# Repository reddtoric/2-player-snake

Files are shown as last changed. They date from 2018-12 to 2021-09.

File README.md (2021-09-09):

# 2-player-snake

2 player snake game in C++ using Arduino Mega, 32x32 LED matrix, custom shield, and two custom 4-button controllers for Adv. Additive Manufacturing (UIC ENGR 294) with updated case.

</br>
<p float="left">
GIF of 2p snake part1
GIF of 2p snake part2
</p>

[Original GIF #1](https://media.giphy.com/media/iEMkRfB8JyjEhcMhLR/giphy.gif) | 
[Original GIF #2](https://media.giphy.com/media/J6tbl7obMBHApaVlm7/giphy.gif)

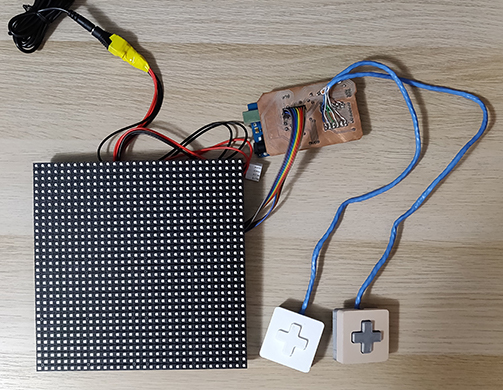
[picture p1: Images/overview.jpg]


</br></br>

<!-- TOC -->

## Table of Contents

- [2-player-snake](#2-player-snake)
  - [D-pad Controller PCB](#d-pad-controller-pcb)
  - [LED Shield for Arduino Mega](#led-shield-for-arduino-mega)
  - [Case](#case)
  - [Updated Case](#updated-case)

<!-- /TOC -->

(Few more pictures included in _Images/_)

## D-pad Controller PCB

Manually figuring out the routes for all 4 buttons.

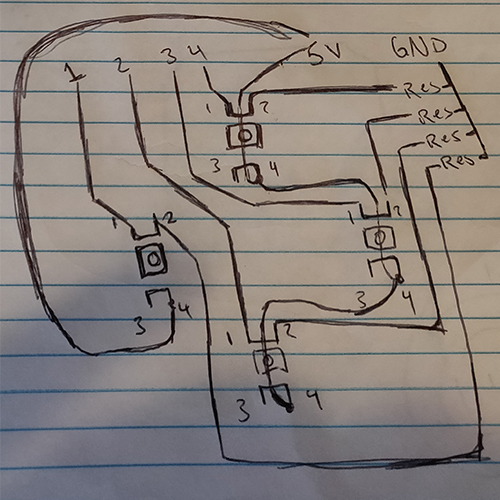
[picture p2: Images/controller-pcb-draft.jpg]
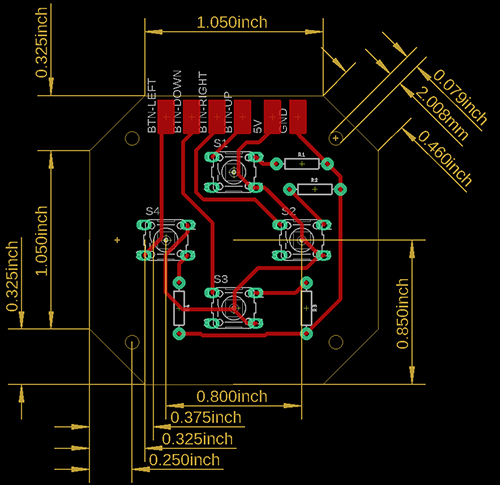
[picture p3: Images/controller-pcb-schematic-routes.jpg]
 
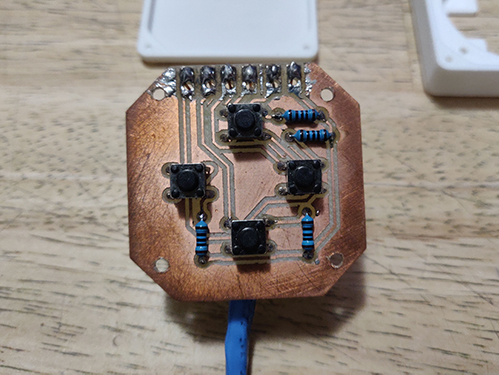
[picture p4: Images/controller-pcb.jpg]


Yes, I know the soldering is ugly.

## LED Shield for Arduino Mega

Also manually routed the shield. Here is the mapping of the 16 pin connector socket for LED matrix and the routes to the Arduino Mega pinouts. The correct mapping might be the horizontal mirrored version; I didn't have a connector cable.

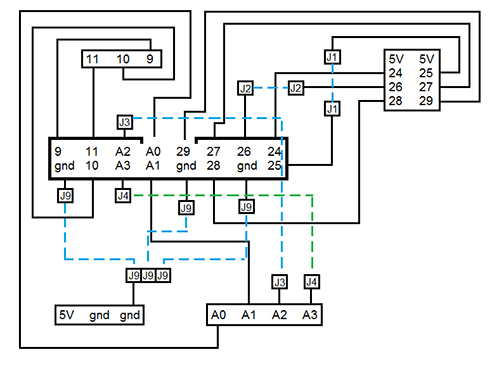
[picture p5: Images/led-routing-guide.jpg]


I only had access to single sided PCB so red PCB routes are on the top/main side and blue routes are on the back that had to be manually connected with wires.

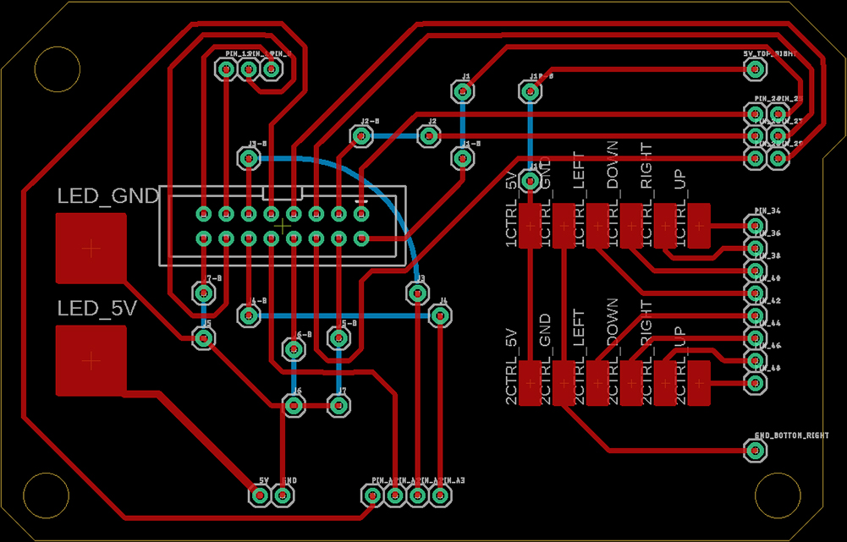
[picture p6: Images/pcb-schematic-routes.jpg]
 </br>
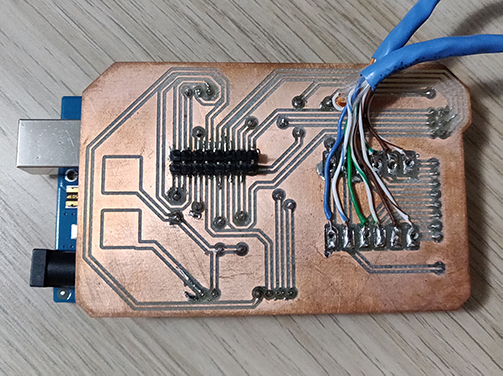
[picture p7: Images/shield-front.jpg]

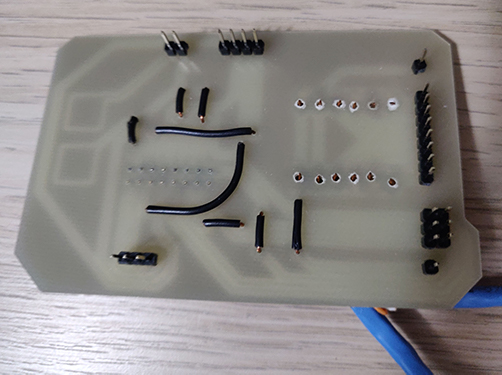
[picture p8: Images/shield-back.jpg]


## Case

Planning and designing the controller cases.

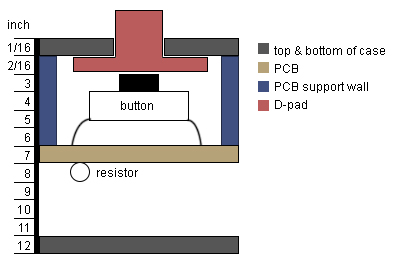
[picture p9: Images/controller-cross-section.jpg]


(Partially) Initial design. I forgot the divot where the soldering on the PCB takes up space. In the original case, you'll see I melted it. Screw holes and cable hole are not in the CAD because I didn't have enough time to make sure they're were they should be and decided to just drill them.

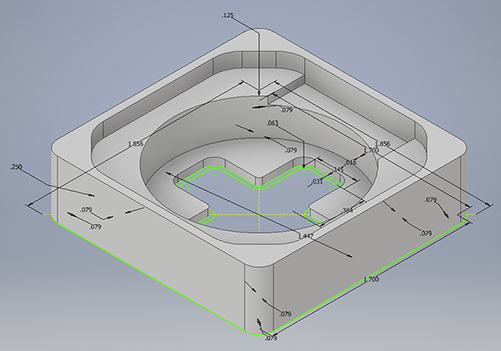
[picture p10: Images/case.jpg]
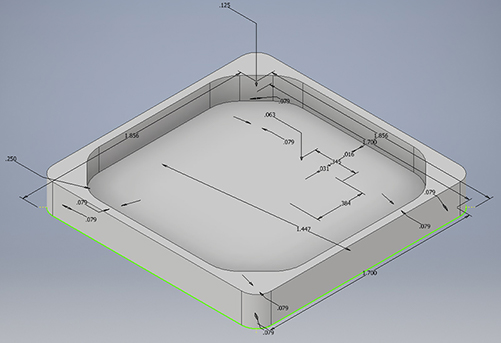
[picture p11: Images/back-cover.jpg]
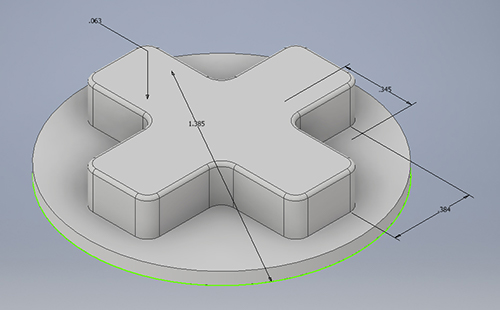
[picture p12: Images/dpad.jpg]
  

Putting it all together.

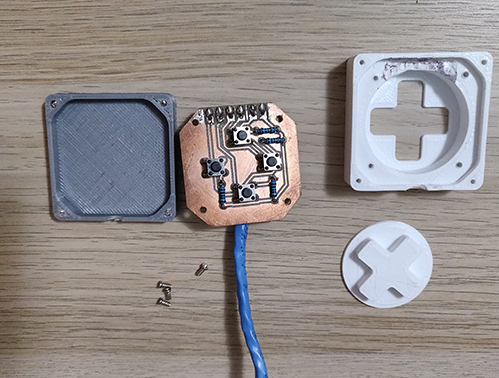
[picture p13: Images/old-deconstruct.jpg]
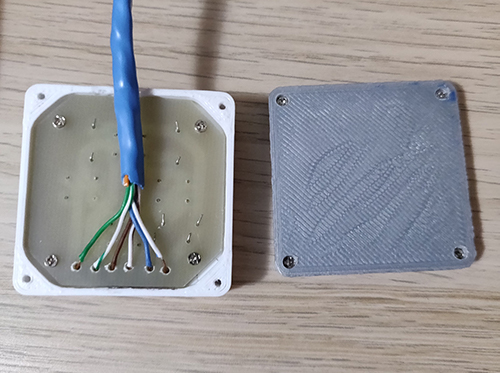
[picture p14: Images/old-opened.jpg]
 

## Updated Case

Added minor changes to the case design. Filet edges, screw holes, tighter tolerances, hole for ethernet cable, and printed with higher quality settings.

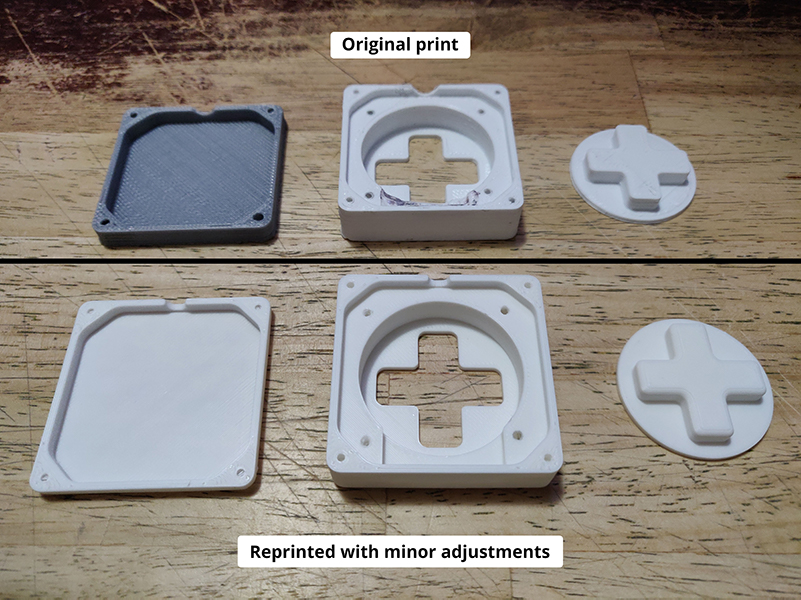
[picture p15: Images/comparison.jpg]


Old:

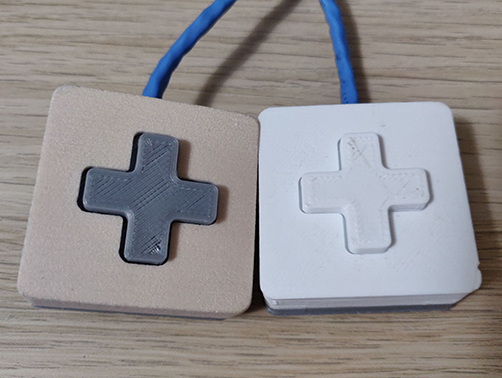
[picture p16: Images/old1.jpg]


New:

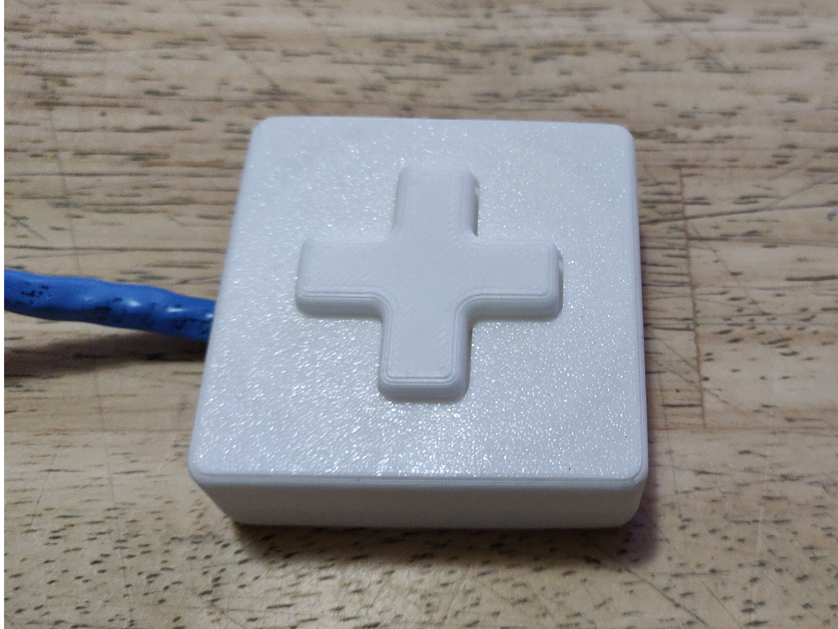
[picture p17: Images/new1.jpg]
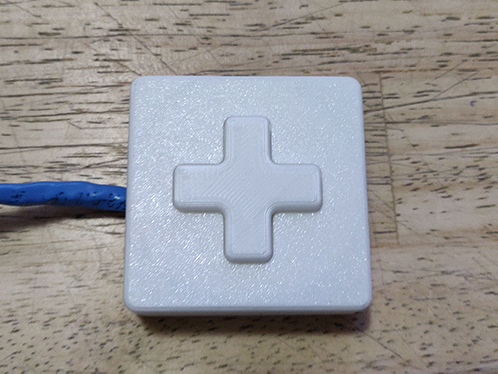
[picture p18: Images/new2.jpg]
 </br>
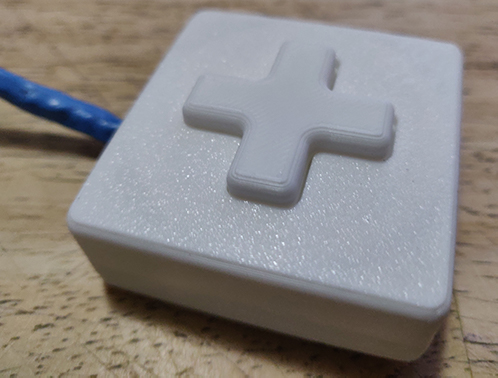
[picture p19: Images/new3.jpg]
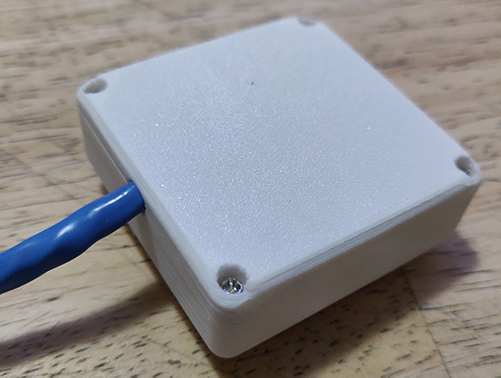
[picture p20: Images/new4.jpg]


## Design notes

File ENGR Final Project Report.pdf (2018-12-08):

University of Illinois at Chicago

# Two-player Snake

ENGR 294 Final Project

Edward Hughes

ENGR 294 Adv. Additive Manufacturing

Dylan Lynch

Fall 2018

ENGR 294 Final Proj. – 2 Player Snake

## Contents

Introduction | 1
Design Details | 1
Overview | 1
Shield | 1
Controller | 4
Controller Case | 6
Arduino Mega Case | 7
Results | 8
Future Ideas | 8

## Figures

Figure 1: Overview | 1
Figure 2: LED Routing Guide | 2
Figure 3: Shield Board | 2
Figure 4A: Shield Schematic | 3
Figure 5: Controller Board | 4
Figure 6: Controller Schematic | 4
Figure 7: First draft of the design for the controller board | 5
Figure 8: Controller Cross Section | 6
Figure 9: Case | 6
Figure 10: Back Cover | 7
Figure 11: D-pad | 7
Figure 12: Arduino Mega Case Design Sketch | 8

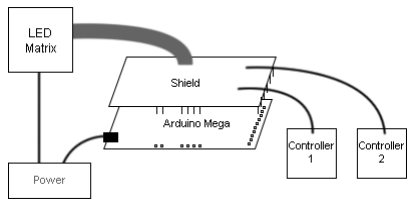
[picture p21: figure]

Edward Hughes | 1

## Introduction

This final project is a two-player snake game using the Arduino Mega and a 32x32 RGB LED matrix.

The classic Snake game on the iconic Nokia is the inspiration for this project. There are plenty of implementations and multiplayer implementations of Snake. The muliplayer ones I have seen have cartoon-like graphics and/or have 360 directional controls which I did not like. Since these implementations didn’t give me the same feeling as the first Snake game I’ve played, I’ve always wanted to make one that was similar to the Snake game I played. I decided to make it two-player because single-player games becomes boring for me.

## Design Details

### Overview

The project consists of a 32x32 RGB LED matrix and 2 PCB boards with 4 buttons each connected to a shield and Arduino Mega.

Figure 1: Overview

### Shield

The shield is the circuit board to connect the LED matrix and the 2 controllers with the Arduino Mega. It’s a single-sided PCB with 8 wires soldered on the back.

I designed the shield in (what I think is) an unconventional. Instead of using the proper parts in the schematic/board or using the appropriate tools to have a route that needed to be routed on the bottom side of the board, I used 2 1-pin-connectors so I can solder a wire to connect them. The bottom (blue) routes shown in Figure 3 show where are the 8 wires should be and they are not actually connected in the schematic/board. These connectors are labeled “J#” and “J#-B” so I know which pair of holes match together.

Figure 2 is a guide I made using Microsoft Paint to help me with how to route each connections for the LED connections. The numbers pairs here are different.

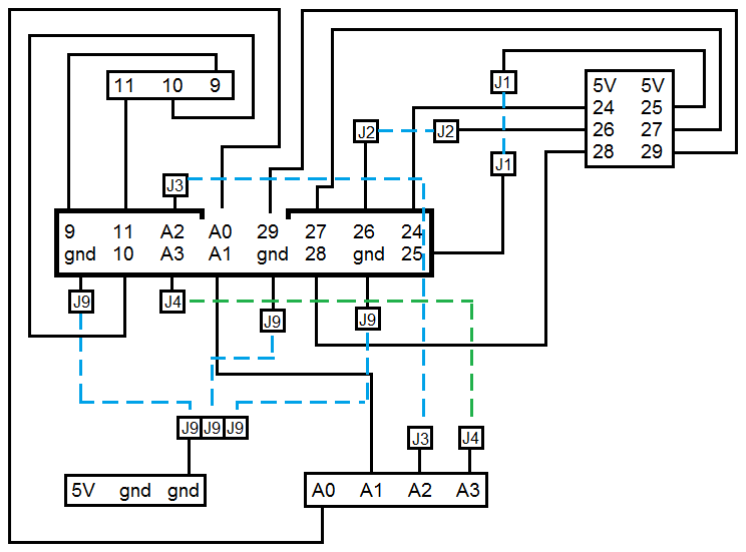
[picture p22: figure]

Figure 2: LED Routing Guide

The shield is a double-sided design because most if not all of the LED connections needed to be connected to certain pins on the Mega. The placement and orientation of the 2x8 headers for the LED matrix is to have each connectors close to the correct pins they are supposed to go and with the least amount of bottom routes needed. The design is not exhaustive so it may be possible to have less than 8 bottom routes. The placement of the 12 pads for the 2 controllers is to be as close to the pins without bottom routes. I learned that I should use connector parts instead of pads when possible because soldering wires on the pads were awfully difficult. I included 2 extra large pads that I created myself on the left in case I were to solder the LED power and ground connectors on the shield.

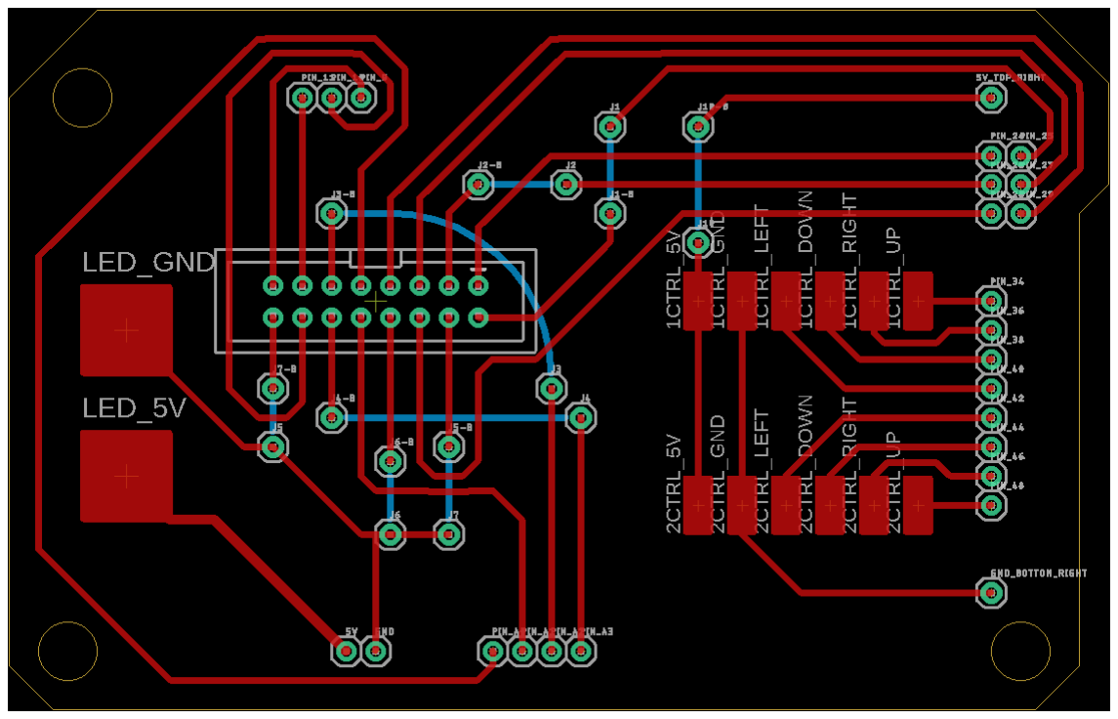
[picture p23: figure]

Figure 3: Shield Board

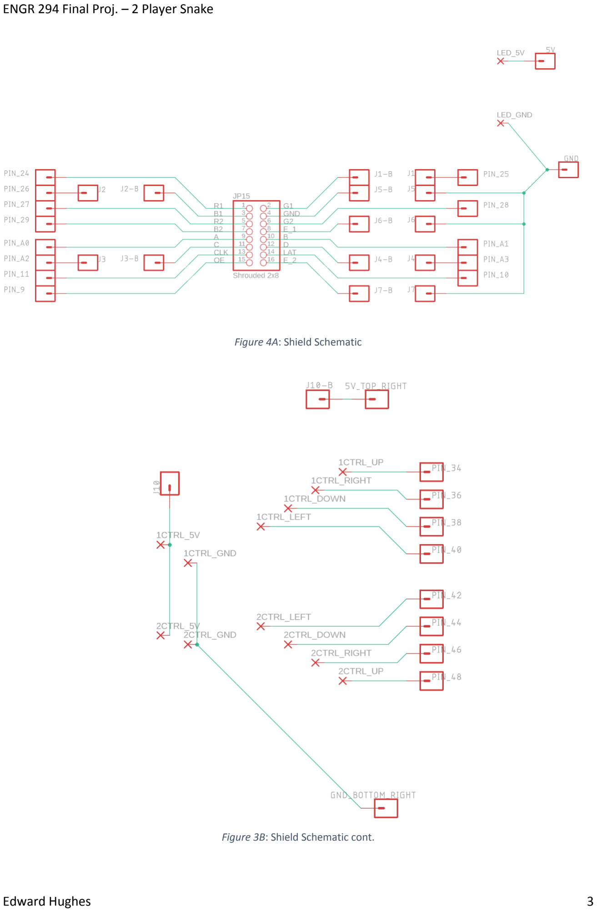
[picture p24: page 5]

Figure 4A: Shield Schematic

Figure 3B: Shield Schematic cont.

### Controller

There are 2 controller PCBs that are exactly the same. They have 4 push buttons each for the 4 possible directions. The buttons are placed so they correspond to the 4 directions and the resistors are placed relatively close to the connected buttons. The pads are placed in that specific “weird” order because it allowed the routes to only be on top side of the PCB. Shown in figure 5, the connections for the left button (S4) are mirror on the horizontal axis compared to the other 3 buttons. This is because initially all the resistors were located on the top right corner which would require either the power and ground connection to be placed on the bottom side of the board. I moved rearranged the resistors from all being in the top right corner to where they are now so the board can be as small as it is now, squared footprint, and with the 4 buttons centered.

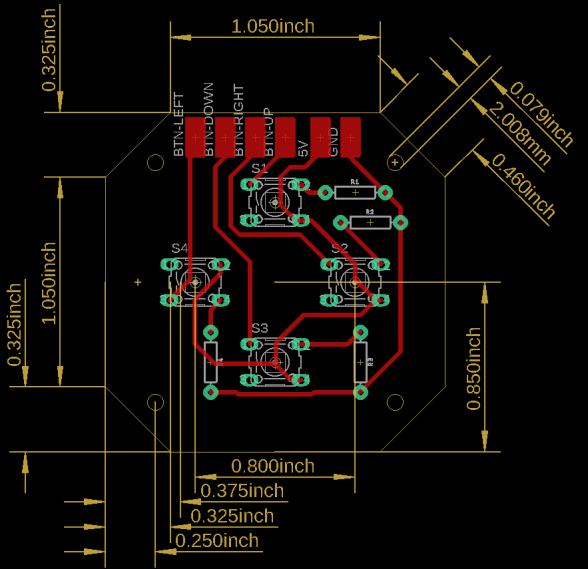
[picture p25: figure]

Figure 5: Controller Board

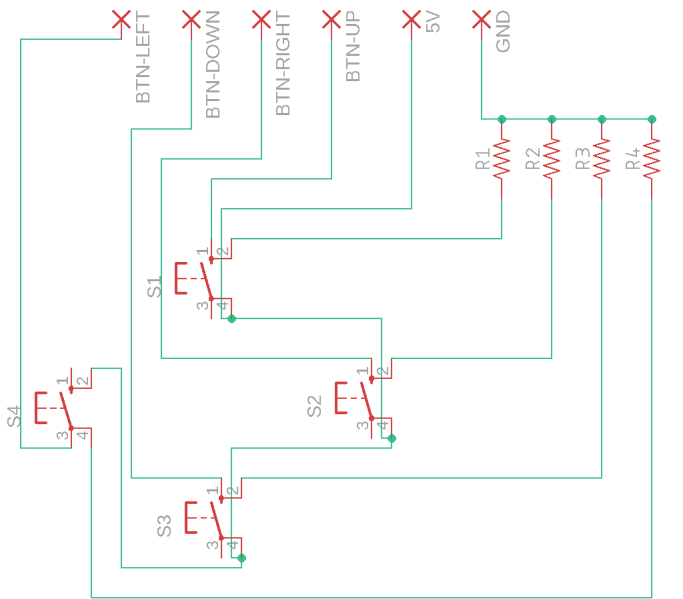
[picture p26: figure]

Figure 6: Controller Schematic

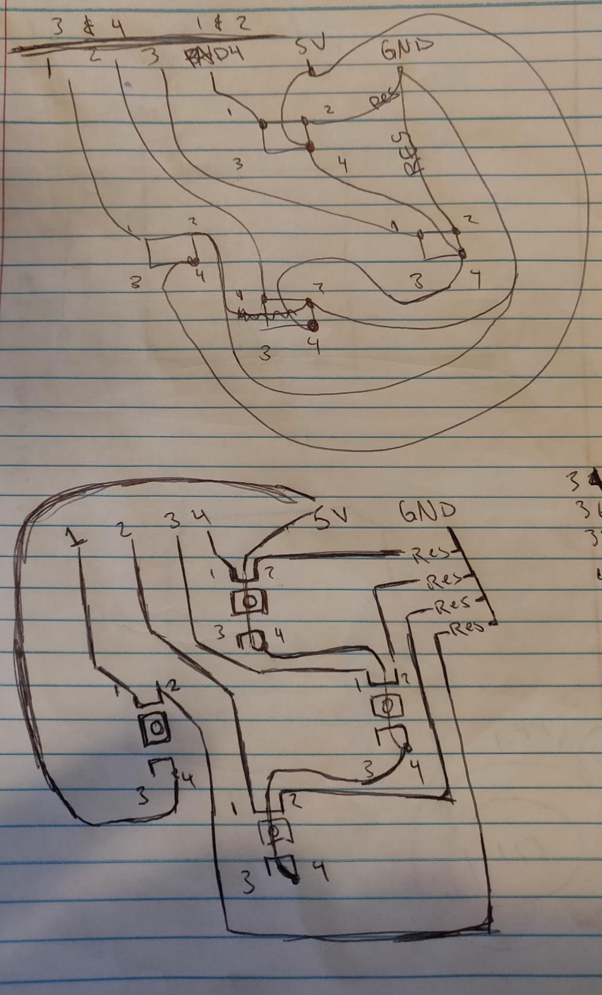
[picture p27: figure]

Figure 7: First draft of the design for the controller board

### Controller Case

There are 3 parts to each case; the main part, the back cover, and the D-pad. The main part is where the controller PCBs would be attached onto. For the most part, it is symetrical on the X and Y axis. The small cutout area on the top right of Figure 9 was added after I realized the 6 pad connections for the controllers were in the way. The design of the case was to be fitted to the controller circuit board and as small as possible. I included about 1/16” or 1/32” of wiggle room for the D-pad and the slot that the circuit board fits in.

Figure 8, is a cleaned up version of a sketch I made to help me figure out what heights I need for the extrusions for the case. In this diagram, the outer side walls are not drawn. The resistor is at the 8/16” mark because that’s where I initially wanted them to be but I end up putting them on the same side as the buttons. With this diagram, the max height of the D-pad would be between 3/16” and 4/16”, I decided to make it 4/16”.

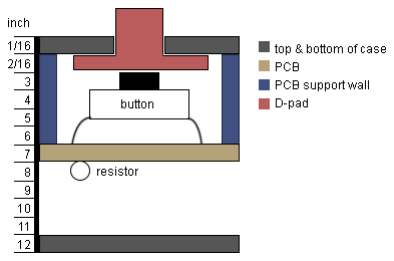
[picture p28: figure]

Figure 8: Controller Cross Section

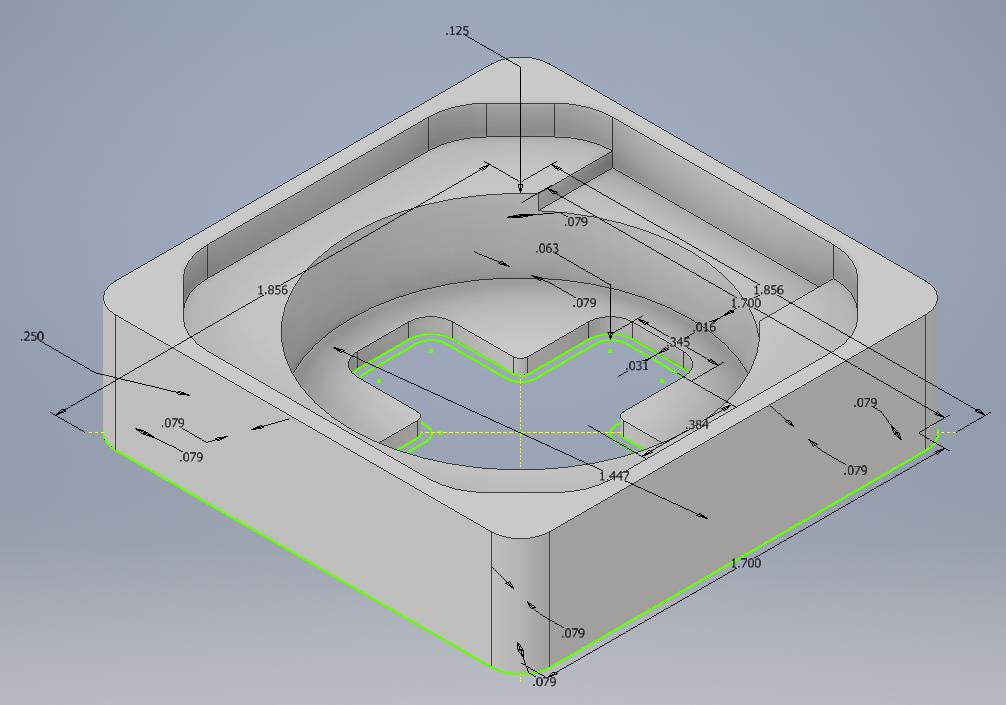
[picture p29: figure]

Figure 9: Case

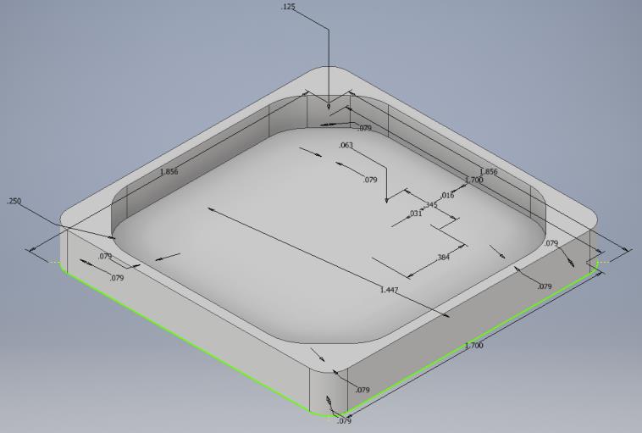
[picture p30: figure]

Figure 10: Back Cover

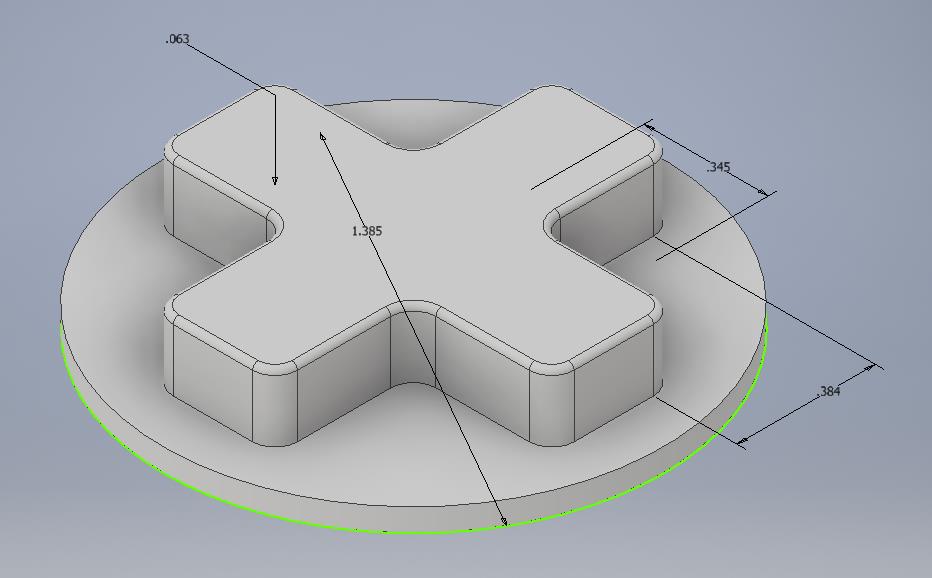
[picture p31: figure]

Figure 11: D-pad

Only 1 of the main part is CNC milled using high density foam. The other is 3D printed along with both back covers and both D-pads.

The Inventor part for the case has toolpath settings for high density foam. The Inventor part for the back cover has toolpath settings for HDPE even though HDPE was not used.

### Arduino Mega Case

Or the lack of a case. I did not create a case for the Arduino Mega, shield, and LED matrix. But if I did, I think it would fit around the Arduino Mega and shield only. The 2 ethernet wires used for connecting the controllers to the case would come out from the top right area of the Mega. And the LED matrix would be attached on the case with 4 arms that would somewhat resemble a speaker.

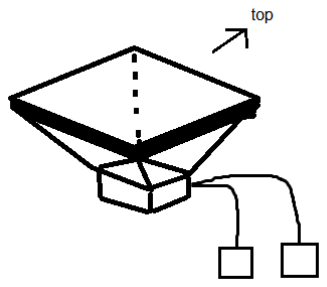
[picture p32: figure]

Figure 12: Arduino Mega Case Design Sketch

## Results

The circuit works and testers enjoyed the game. I enjoyed designing and creating the CAD files, program, and circuitry. Three other people outside of MakerSpace and class tested the game and liked the game and the two-player idea.

## Future Ideas

If I thought about and decided on this idea earlier, I would have been able to get RF modules and the appropriate chips to make the controllers wireless while keeping the designs fairly small. Other alternatives that don’t make sense but still works is to use small bluetooth modules and small microcontrollers to drive the 2 controllers.

I can polish up the coding for this two-player snake and also create a starting menu and a better gameover menu. Selection of colors and speed. Multiple food/apples. More than 2 players. As well as creating other games like Pong, Tetris, Pac-Man, and Tron.

Seeing the amount of positive feedback, I’m inspired and motivated to create a PC/Mac/Linux game based on this using Unity (game engine). The game would most likely have 2D “boards” in a 3D world where you can teleport between the boards. The boards are not all rectangular, they could be different shapes.

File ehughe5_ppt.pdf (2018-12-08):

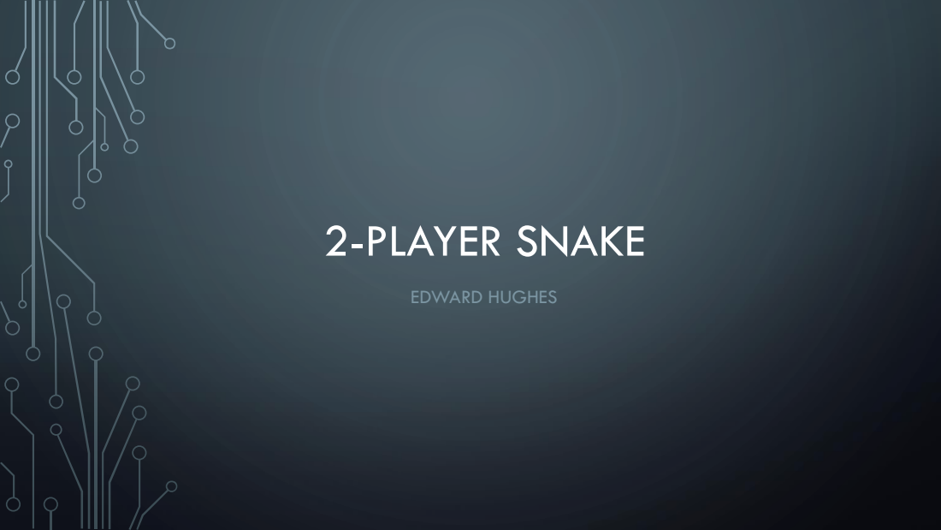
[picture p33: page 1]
2-PLAYER SNAKE; EDWARD HUGHES

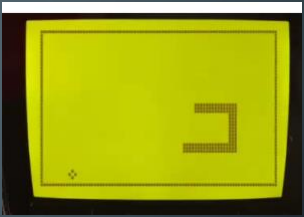
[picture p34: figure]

## INSPIRATION

- Classic Snake game on the iconic

Nokia phone

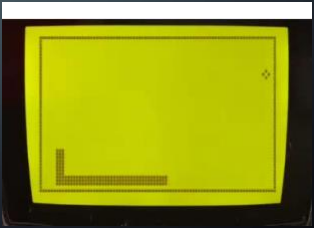
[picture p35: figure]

- Single player is boring so that’s why

this is 2-player

## BIG PICTURE

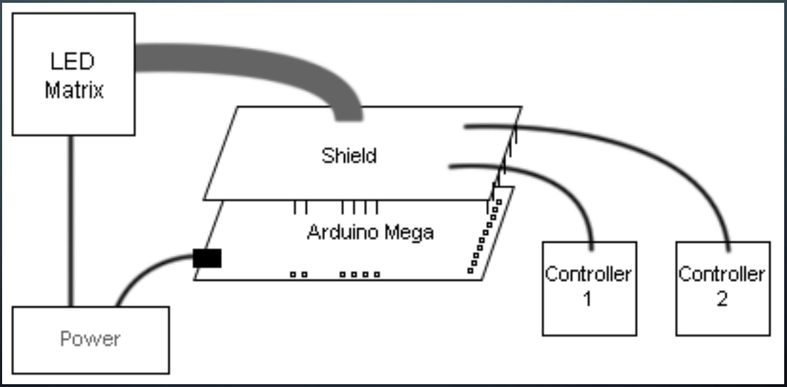
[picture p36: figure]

## SHIELD DESIGN

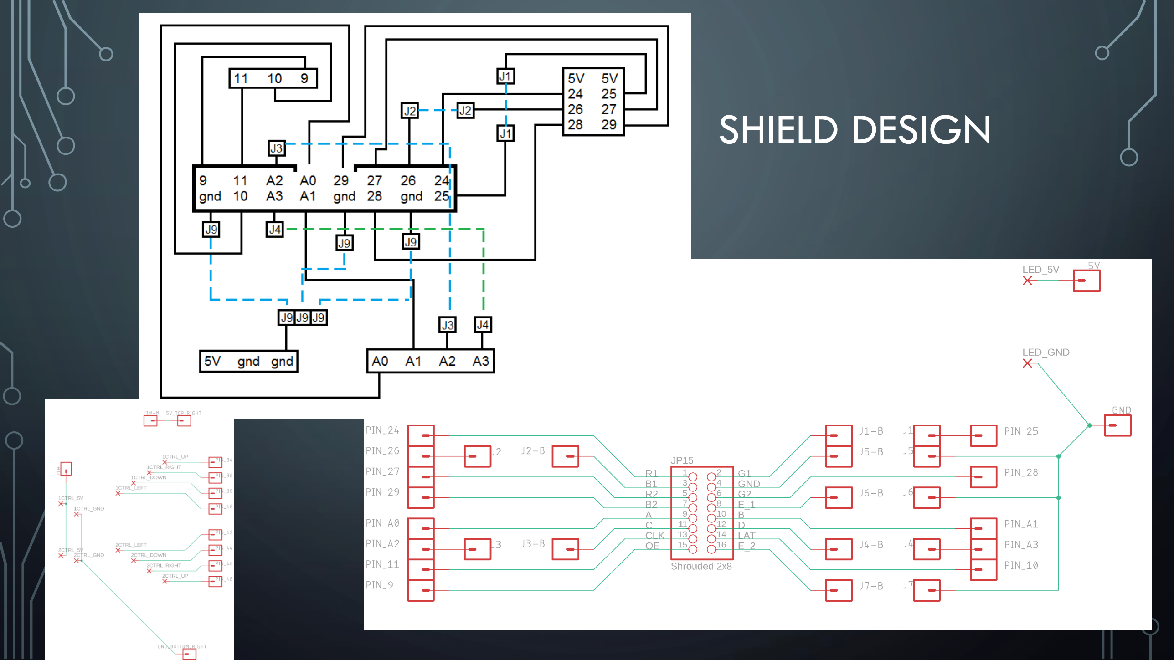
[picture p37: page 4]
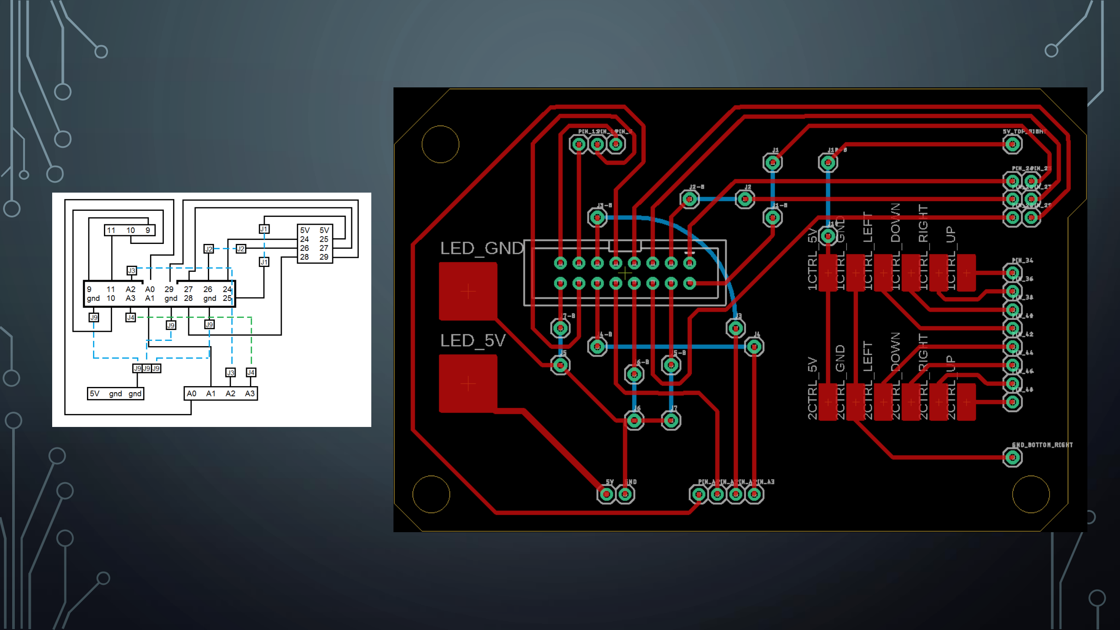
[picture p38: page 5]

## CONTROLLER PCB DESIGN

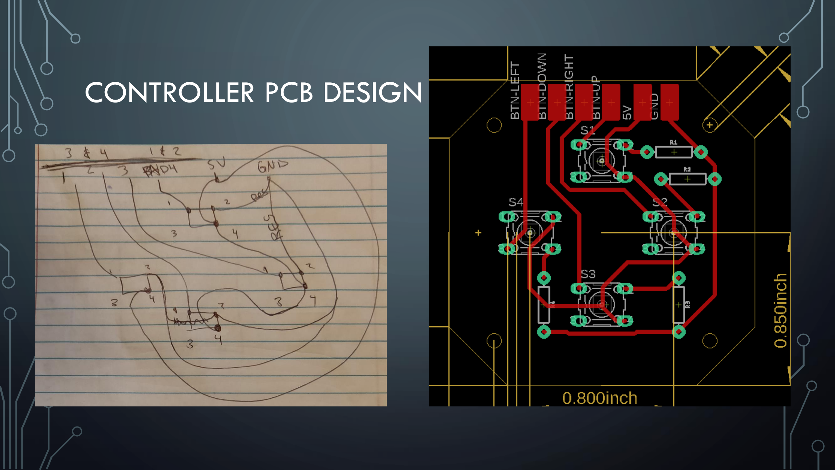
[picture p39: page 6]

## CONTROLLER CASE DESIGN

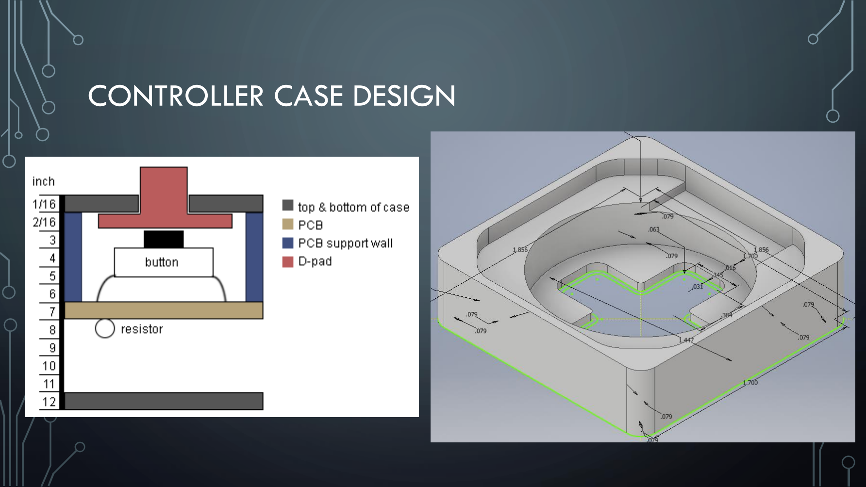
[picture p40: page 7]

## 3 PIECE CASE

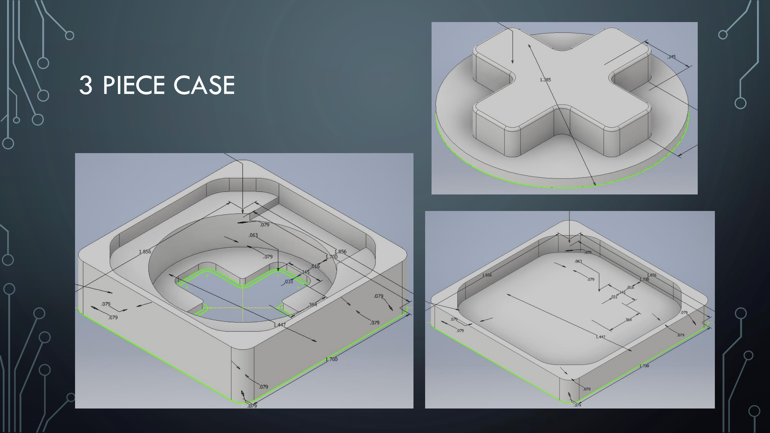
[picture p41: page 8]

## FUTURE IDEAS

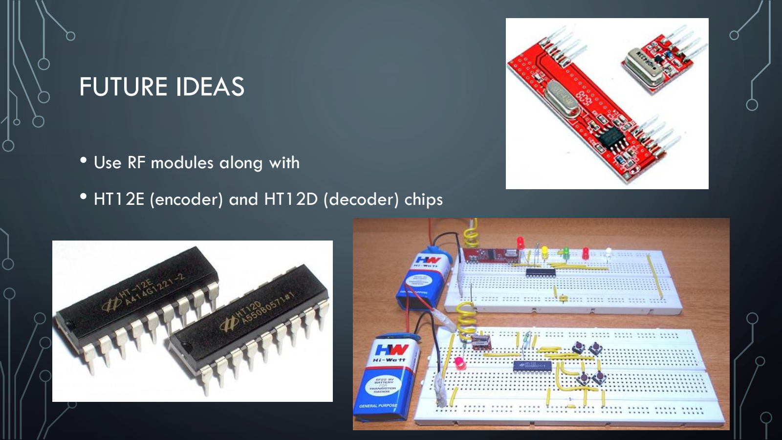
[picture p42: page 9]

- Use RF modules along with
- HT12E (encoder) and HT12D (decoder) chips

## FUTURE IDEAS 2

- Polish the code and add selection of colors, speed, difficulty
- Add multiple food and more than 2 players
- Implement other games like Tron, Pac-Man, Tetris, and Pong

## FUTURE IDEAS 3

- Make PC/Mac/Linux game based on this using Unity (game engine) and

inspired by 4D chess (the “teleporting” part)

- Instead of a plain vanilla 2D board or cartoonlike graphics
- 2D boards placed in a 3D world and to travel between the 2D boards,

players go to a certain spot to teleport to corresponding teleport terminal

- Non rectangular board shapes
- Information about this will be published on EdDevs.com (if I really make it)

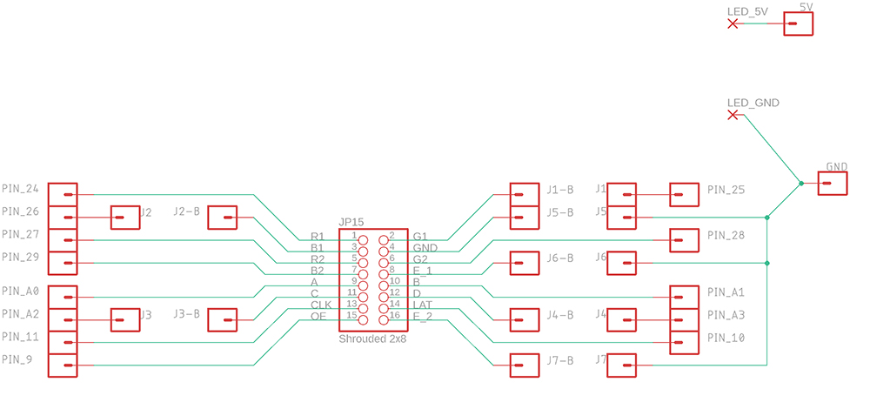
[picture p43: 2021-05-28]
Images/shield-schematic.jpg

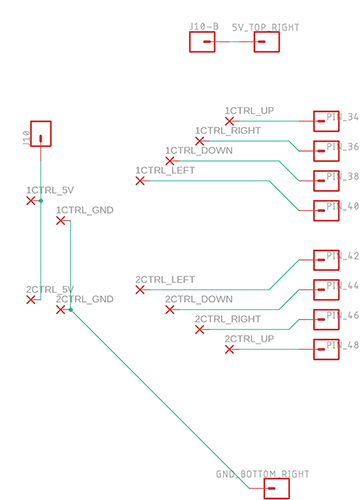
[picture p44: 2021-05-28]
Images/shield-schematic-2.jpg

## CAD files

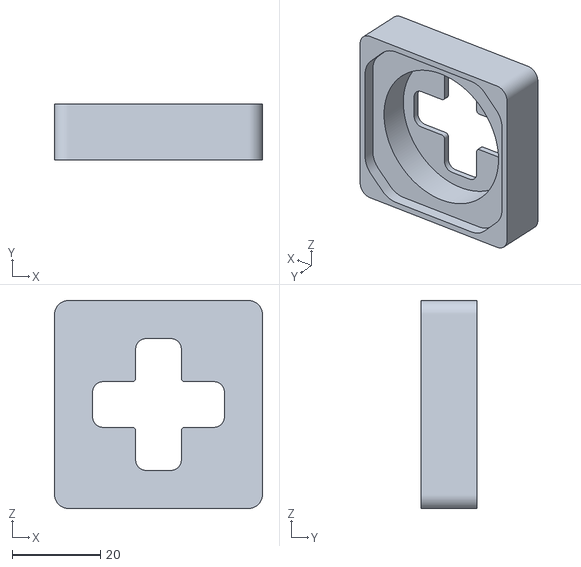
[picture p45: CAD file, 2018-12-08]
CAD Designs/3D Print Files/SnakeControllerCase_v3_withCNCsetup.stl
47.1 x 12.7 x 47.1

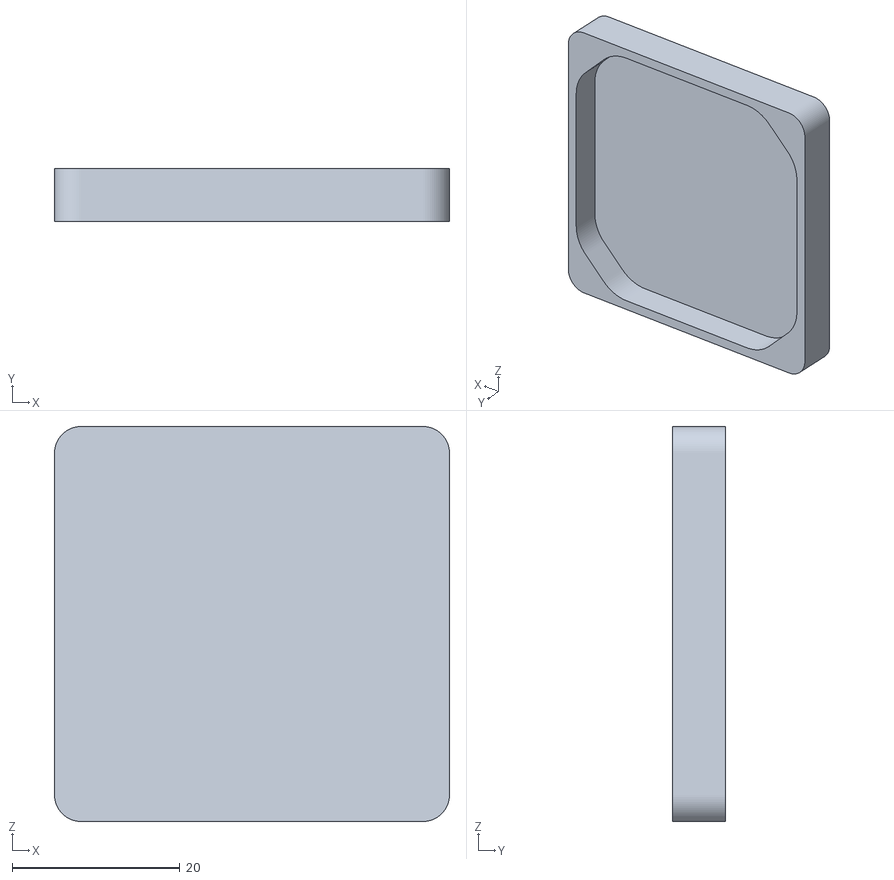
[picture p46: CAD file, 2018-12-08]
CAD Designs/3D Print Files/SnakeControllerCaseBackCover_v4_withCNCsetup.stl
47.1 x 6.35 x 47.1

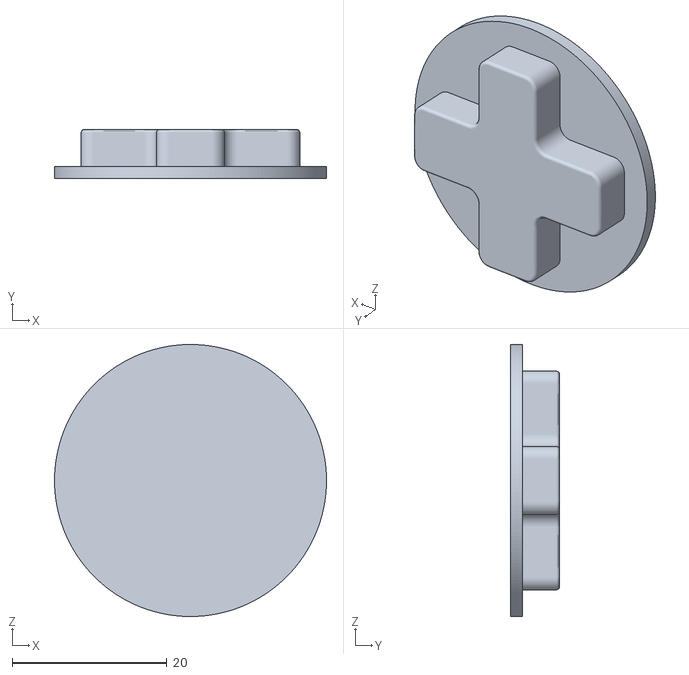
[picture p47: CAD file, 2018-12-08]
CAD Designs/3D Print Files/SnakeControllerDPad_v3.stl
35.2 x 6.35 x 35.2

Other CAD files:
Archive/CAD Designs/SnakeControllerCaseBackCover_v4_withCNCsetup.ipt
Archive/CAD Designs/SnakeControllerCase_v4_withCNCsetup.ipt
Archive/CAD Designs/SnakeControllerDPad_v3.ipt
CAD Designs/SnakeControllerCaseBackCover_v4_withCNCsetup.ipt
CAD Designs/SnakeControllerCase_v4_withCNCsetup.ipt
CAD Designs/SnakeControllerDPad_v3.ipt

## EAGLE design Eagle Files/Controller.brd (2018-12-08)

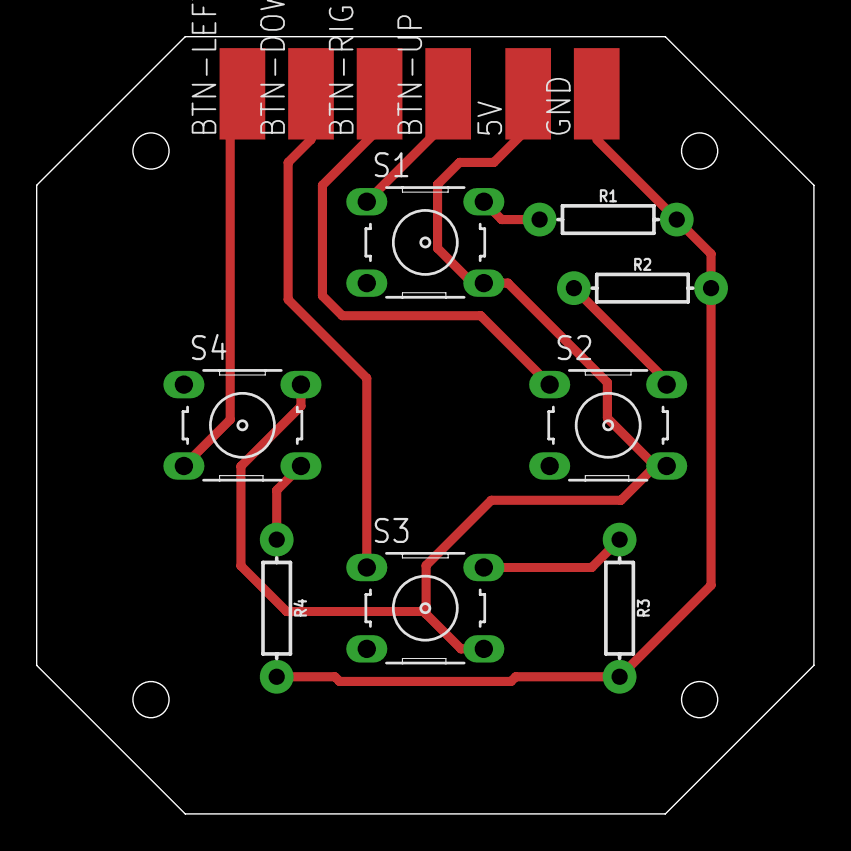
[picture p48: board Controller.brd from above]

Board: 2 copper layers, 43.2 x 43.2 mm, 14 parts (0 on the bottom side), 10 nets.

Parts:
5V: SMD2,54-5,08
BTN-DOWN: SMD2,54-5,08
BTN-LEFT: SMD2,54-5,08
BTN-RIGHT: SMD2,54-5,08
BTN-UP: SMD2,54-5,08
GND: SMD2,54-5,08
R1, R2, R3, R4: AXIAL-0.3
S1, S2, S3, S4: B3F-10XX

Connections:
unnamed: BTN-DOWN.1, S3.1
unnamed: BTN-RIGHT.1, S2.1
unnamed: BTN-UP.1, S1.1
unnamed: BTN-LEFT.1, S4.3
unnamed: GND.1, R1.P$2, R2.P$2, R3.P$2, R4.P$2
unnamed: R1.P$1, S1.2
unnamed: R2.P$1, S2.2
unnamed: R3.P$1, S3.2
unnamed: R4.P$1, S4.4
unnamed: 5V.1, S1.4, S2.4, S3.4, S4.2

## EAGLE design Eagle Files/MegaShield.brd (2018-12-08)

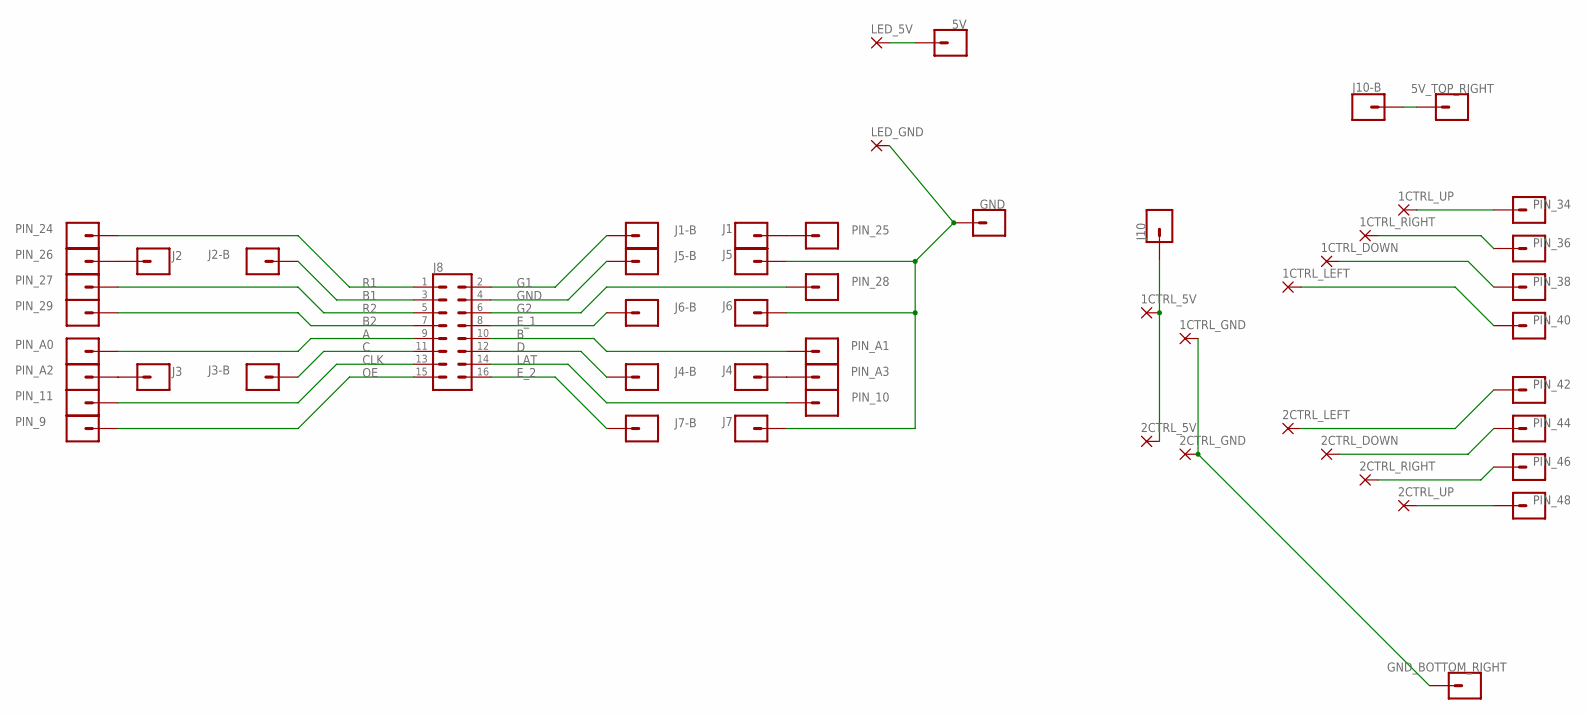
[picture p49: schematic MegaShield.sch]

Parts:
1CTRL_5V, 1CTRL_DOWN, 1CTRL_GND, 1CTRL_LEFT, 1CTRL_RIGHT, 1CTRL_UP, 2CTRL_5V, 2CTRL_DOWN, 2CTRL_GND, 2CTRL_LEFT, 2CTRL_RIGHT, 2CTRL_UP: PADSMALL; SMD2,54-5,08
5V, 5V_TOP_RIGHT: CONN_01; 1X01
GND: CONN_01; 1X01
GND_BOTTOM_RIGHT: CONN_01; 1X01
J1, J1-B, J2, J2-B, J3, J3-B, J4, J4-B, J5, J5-B, J6, J6-B, J7, J7-B, J10, J10-B: CONN_01; 1X01
J8: CONN_08X2_SHROUD; 2X8-SHROUDED_LOCK
LED_5V: PAD_EXLARGE; SMD_EXLARGE
LED_GND: PAD_EXLARGE; SMD_EXLARGE
PIN_9, PIN_10, PIN_11, PIN_24, PIN_25, PIN_26, PIN_27, PIN_28, PIN_29, PIN_34, PIN_36, PIN_38, PIN_40, PIN_42, PIN_44, PIN_46, PIN_48: CONN_01; 1X01
PIN_A0, PIN_A1, PIN_A2, PIN_A3: CONN_01; 1X01

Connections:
A: J8.9, PIN_A0.1
B: J8.10, PIN_A1.1
B1: J2-B.1, J8.3
B2: J8.7, PIN_29.1
C: J3-B.1, J8.11
CLK: J8.13, PIN_11.1
D: J4-B.1, J8.12
E_1: J6-B.1, J8.8
E_2: J7-B.1, J8.16
G1: J1-B.1, J8.2
G2: J8.6, PIN_28.1
GND: J5-B.1, J8.4
LAT: J8.14, PIN_10.1
unnamed: J2.1, PIN_26.1
unnamed: J3.1, PIN_A2.1
unnamed: J1.1, PIN_25.1
unnamed: 5V.1, LED_5V.P$1
unnamed: GND.1, J5.1, J6.1, J7.1, LED_GND.P$1
unnamed: J4.1, PIN_A3.1
unnamed: 1CTRL_UP.1, PIN_34.1
unnamed: 1CTRL_RIGHT.1, PIN_36.1
unnamed: 1CTRL_DOWN.1, PIN_38.1
unnamed: 1CTRL_LEFT.1, PIN_40.1
unnamed: 2CTRL_UP.1, PIN_48.1
unnamed: 2CTRL_RIGHT.1, PIN_46.1
unnamed: 2CTRL_DOWN.1, PIN_44.1
unnamed: 5V_TOP_RIGHT.1, J10-B.1
unnamed: 1CTRL_5V.1, 2CTRL_5V.1, J10.1
unnamed: 1CTRL_GND.1, 2CTRL_GND.1, GND_BOTTOM_RIGHT.1
unnamed: 2CTRL_LEFT.1, PIN_42.1
OE: J8.15, PIN_9.1
R1: J8.1, PIN_24.1
R2: J8.5, PIN_27.1

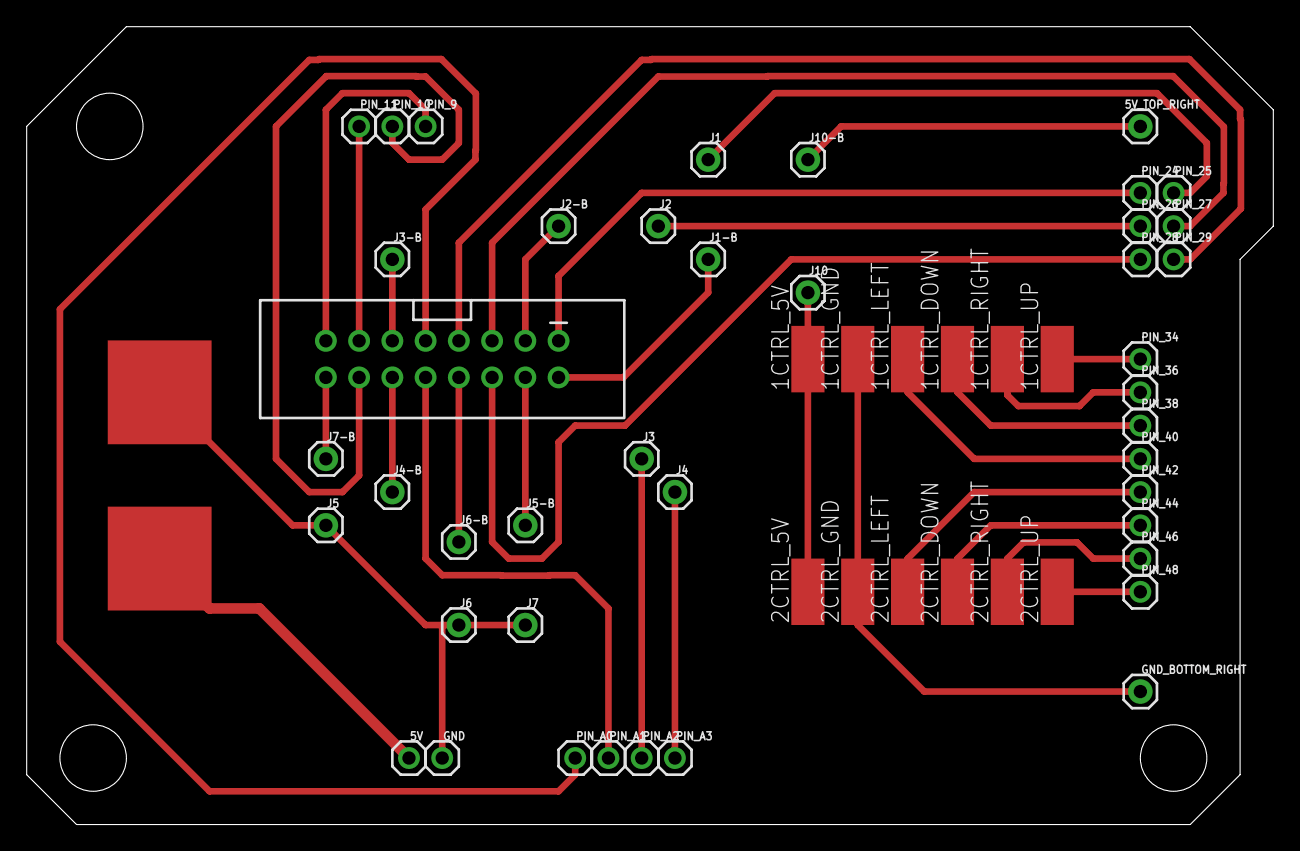
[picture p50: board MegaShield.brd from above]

Board: 2 copper layers, 95.2 x 61.0 mm, 56 parts (0 on the bottom side), 33 nets.

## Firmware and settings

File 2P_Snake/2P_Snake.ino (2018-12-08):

#include <LinkedList.h> //https://github.com/ivanseidel/LinkedList
#include <gamma.h>
#include <RGBmatrixPanel.h>


//speed of game & frame rate
//lower number = faster, higher number = slower
int speed = 150;

//dimension of led matrix
#define MAX_X 32
#define MAX_Y 32



//player 1 d-pad
#define P1_LEFT 36
#define P1_DOWN 34
#define P1_RIGHT 40
#define P1_UP 38

//player 2 d-pad
#define P2_LEFT 46
#define P2_DOWN 48
#define P2_RIGHT 42
#define P2_UP 44

enum Direction {
  up,
  down,
  left, 
  right
};

typedef struct Position {
  int x;
  int y;
};

typedef struct Player{
  LinkedList <Position> snake;
  int length;
  Direction direction;
};

//Arduino Mega pins
RGBmatrixPanel matrix(A0, A1, A2, A3, 11, 10, 9, false);

bool gameover = false;

Player p1;
Player p2;
Position food;

int p1Up;
int p1Down;
int p1Left;
int p1Right;

int p2Up;
int p2Down;
int p2Left;
int p2Right;

unsigned long previousTime;
unsigned long currentTime;
unsigned long elapsedTime;


//check validity of food position
bool isValidFoodPosition(){
  Position slice;

  //check against snake 1
  int n = p1.length;
  for (int i = 0; i < n; i++){
    slice = p1.snake.get(i);
    if (food.x == slice.x && food.y == slice.y){
      return false;
    }
  }
  
  //check against snake 2
  n = p2.length;
  for (int i = 0; i < n; i++){
    slice = p2.snake.get(i);
    if (food.x == slice.x && food.y == slice.y){
      return false;
    }
  }

  //food is not on any snake position = valid
  return true;
}

//spawn food on valid position
void spawnFood(){
  while(!isValidFoodPosition()){
    food = randomPosition();
  }
}

//spawn both snakes
void spawnSnakes(){
  p1.snake.unshift(randomPosition());
  p1.length = 1;
  p1.direction = randomDirection();
  
  Position tmp;
  do {
    tmp = randomPosition();
  }
  while(tmp.x != p1.snake.get(0).x && tmp.y != p1.snake.get(0).y);

  p2.snake.unshift(tmp);
  p2.length = 1;
  p2.direction = randomDirection();
}

void eat(){
  if (food.x == p1.snake.get(0).x && food.y == p1.snake.get(0).y){
    spawnFood();
    p1.snake.add(p1.snake.get(p1.snake.size()-1));
    p1.length = p1.snake.size();
  }
  if (food.x == p2.snake.get(0).x && food.y == p2.snake.get(0).y){
    spawnFood();
    p2.snake.add(p2.snake.get(p2.snake.size()-1));
    p2.length = p2.snake.size();
  }
}

void move(){
  Position newSnakeHead;
  newSnakeHead.x = p1.snake.get(0).x + ((p1.direction == left)  ? -1 : ((p1.direction == right)  ? 1 : 0));
  newSnakeHead.y = p1.snake.get(0).y + ((p1.direction == up)    ? -1 : ((p1.direction == down)   ? 1 : 0));

  newSnakeHead.x = (newSnakeHead.x < 0) ? MAX_X-1 : ((newSnakeHead.x >= MAX_X) ? 0 : newSnakeHead.x);
  newSnakeHead.y = (newSnakeHead.y < 0) ? MAX_Y-1 : ((newSnakeHead.y >= MAX_Y) ? 0 : newSnakeHead.y);

  p1.snake.unshift(newSnakeHead);
  //pop tail
  p1.snake.pop();

  
  newSnakeHead.x = p2.snake.get(0).x + ((p2.direction == left)  ? -1 : ((p2.direction == right)  ? 1 : 0));
  newSnakeHead.y = p2.snake.get(0).y + ((p2.direction == up)    ? -1 : ((p2.direction == down)   ? 1 : 0));

  newSnakeHead.x = (newSnakeHead.x < 0) ? MAX_X-1 : ((newSnakeHead.x >= MAX_X) ? 0 : newSnakeHead.x);
  newSnakeHead.y = (newSnakeHead.y < 0) ? MAX_Y-1 : ((newSnakeHead.y >= MAX_Y) ? 0 : newSnakeHead.y);

  p2.snake.unshift(newSnakeHead);
  //pop tail
  p2.snake.pop();
}

Direction randomDirection(){
  return (Direction)random(0, 4);
}

Position randomPosition(){
  return {random(0, MAX_X), random(0, MAX_Y)};
}

void clearFrame(){
  matrix.fillScreen(matrix.Color333(0, 0, 0));
}

void displayFrame(){
  matrix.drawPixel(food.x, food.y, matrix.Color333(7,0,0));

  Position snakeSlice;
  int n = p1.snake.size();
  for(int i = 0; i < n; i++){
    snakeSlice = p1.snake.get(i);
    matrix.drawPixel(snakeSlice.x, snakeSlice.y, matrix.Color333(5, 5, 5));
  }

  n = p2.snake.size();
  for(int i = 0; i < n; i++){
    snakeSlice = p2.snake.get(i);
    matrix.drawPixel(snakeSlice.x, snakeSlice.y, matrix.Color333(0, 0, 5));
  }
}

void check(){
  Position snakeHead = p1.snake.get(0);
  int n = p2.snake.size();
  for(int i = 0; i < n; i++){
    Position snakeSlice = p2.snake.get(i);
    if (snakeHead.x == snakeSlice.x && snakeHead.y == snakeSlice.y){
      gameover = true;
    }
  }

  snakeHead = p2.snake.get(0);
  n = p1.snake.size();
  for(int i = 0; i < n; i++){
    Position snakeSlice = p1.snake.get(i);
    if (snakeHead.x == snakeSlice.x && snakeHead.y == snakeSlice.y){
      gameover = true;
    }
  }
}

void reset(){
  p1.snake.clear();
  p2.snake.clear();
}

void setup() {
  matrix.begin();
  Serial.begin(9600);
  randomSeed(analogRead(0));

  pinMode(P1_UP, INPUT);
  pinMode(P1_DOWN, INPUT);
  pinMode(P1_LEFT, INPUT);
  pinMode(P1_RIGHT, INPUT);
  
  pinMode(P2_UP, INPUT);
  pinMode(P2_DOWN, INPUT);
  pinMode(P2_LEFT, INPUT);
  pinMode(P2_RIGHT, INPUT);
  
  
  spawnSnakes();
  spawnFood();
}

void loop() {
  currentTime = millis();
  elapsedTime = currentTime - previousTime;

  if (!gameover){
    p1Up = digitalRead(P1_UP);
    p1Down = digitalRead(P1_DOWN);
    p1Left = digitalRead(P1_LEFT);
    p1Right = digitalRead(P1_RIGHT);
    
    p2Up = digitalRead(P2_UP);
    p2Down = digitalRead(P2_DOWN);
    p2Left = digitalRead(P2_LEFT);
    p2Right = digitalRead(P2_RIGHT);
    
    p1.direction = (p1Up == HIGH && p1.direction != down) ? up : p1.direction;
    p1.direction = (p1Down == HIGH && p1.direction != up) ? down : p1.direction;
    p1.direction = (p1Left == HIGH && p1.direction != right) ? left : p1.direction;
    p1.direction = (p1Right == HIGH && p1.direction != left) ? right : p1.direction;
    
    p2.direction = (p2Up == HIGH && p2.direction != down) ? up : p2.direction;
    p2.direction = (p2Down == HIGH && p2.direction != up) ? down : p2.direction;
    p2.direction = (p2Left == HIGH && p2.direction != right) ? left : p2.direction;
    p2.direction = (p2Right == HIGH && p2.direction != left) ? right : p2.direction;
    
    if (elapsedTime > speed){
      clearFrame();
      displayFrame();
      
      move();
      eat();
      check();
      previousTime = currentTime;
    }
  }
  else{
    clearFrame();
    matrix.setCursor(2, 0);    // start at top left, with one pixel of spacing
    matrix.setTextSize(1);     // size 1 == 8 pixels high
    matrix.setTextWrap(false); // Don't wrap at end of line - will do ourselves
    
    matrix.setTextColor(matrix.Color333(0,0,5));
    matrix.println("game");
    matrix.println(" over");

    matrix.println("  3");
    delay(1000);
    
    matrix.setCursor(2, 0);
    matrix.fillScreen(matrix.Color333(0, 0, 0));
    matrix.setTextColor(matrix.Color333(0,0,5));
    matrix.println("game");
    matrix.println(" over");
    matrix.println("  2");
    delay(1000);
    
    matrix.setCursor(2, 0);
    matrix.fillScreen(matrix.Color333(0, 0, 0));
    matrix.setTextColor(matrix.Color333(0,0,5));
    matrix.println("game");
    matrix.println(" over");
    matrix.println("  1");
    delay(1000);

    reset();
    spawnSnakes();
    spawnFood();
    gameover = false;
  }
}

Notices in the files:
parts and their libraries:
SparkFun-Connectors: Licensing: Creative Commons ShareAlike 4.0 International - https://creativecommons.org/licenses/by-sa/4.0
